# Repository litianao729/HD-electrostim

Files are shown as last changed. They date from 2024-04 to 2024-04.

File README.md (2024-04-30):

# A scalable, non-invasive, high-frequency stimulator for tactile sensory feedback

# Description
This project is used to support the thesis and paper. A scalable, non-invasive, high-frequency stimulator is developed in this work for tactile sensory feedback. The hardware design files, and software program files are contained in this GitHub project.
# Instruction
The folder named pcb contains three folders which correspond to three separate PCB boards of the stimulator. For each folder, the file with extension of .kicad_pro can be opened by KiCad software. One can modify the schematics and PCB layouts for a specific PCB design project. To utilize the design:
1.	Find the folder has “gerber” in its name. This folder contains the information to fabricate the board. 
2.	Upload that folder (or compress before uploading) to a PCB fabrication server such as PCBway. 
3.	Assemble the boards according to the components listed in the table with an extension name of .csv.
Software program codes to control the stimulator are saved in the rest folders. Folders named whole_time_current_pulse and whole_time_voltage_pulse only has Arduino IDE sketch. These sketches are example codes to run the stimulator producing endless square waveform with constant current or voltage amplitude. To utilize these codes:
1.	Download the entire folder and open the sketch (extension name is .ino) via Arduino IDE.
2.	Upload the sketch to the stimulator (connected with your laptop).
3.	Measure the signal from the electrode outputs (align with the settings in the sketch).
Folder named switching_speed_test only has Arduino sketch. This sketch is used to test the switch speed of the electrode switchboard of the stimulator. To utilize this code:
1.	Download the entire folder and open the sketch (extension name is .ino) via Arduino IDE.
2.	Upload the sketch to the stimulator (connected with your laptop).
3.	Measure the signal from the electrode outputs (align with the settings in the sketch) with a oscilloscope to observe the time delay between electrode disconnection and reconnection (electrode switching event is defined as a disconnection of the old electrode and a connection of another electrode)
Other folders contain not only Arduino IDE sketch but also MATLAB script (extension name: .m) or live script (extension name: .mlx). The MATLAB scripts determine the values of the parameters defined in the Arduino IDE sketches. By serial communication, these values are transferred to the IDE interface. For each folder, to utilize the codes:
Download the folder. Open the Arduino IDE sketch and MATLAB script with Arduino IDE and MATLAB respectively.
Upload the sketch to the stimulator (connected with your laptop).
Run the first section in the MATLAB script (to establish serial communication between MATLAB and Arduino IDE).
If there is no error, run the rest sections of the script.
For live script, interactive controls are used to define the parameter values. One can change the values as the program is running.

# Notifications and troubleshooting:
The connection between MATLAB and Arduino IDE is achieved through serial communication. When using MATLAB script as the parameter inputs, you cannot use Serial monitor tool of the Arduino IDE.
Sometimes error might occur when running the first section of the MATLAB script to establish serial communication. To solve this issue, you can check if serial monitor tool is being used and reupload the sketch.

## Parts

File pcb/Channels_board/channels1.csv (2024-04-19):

Source: | /Users/tianaoli/Library/CloudStorage/OneDrive-JohnsHopkins/Electrostimulator/electrostimulatorv3/electrostimulatorV3_pcbdesign/channels1/channels1.kicad_sch
Date: | 2023 December 08, Friday 15:54:42
Tool: | Eeschema 7.0.6-0
Generator: | /Applications/KiCad/KiCad.app/Contents/SharedSupport/plugins/bom_csv_grouped_by_value_with_fp.py
Component Count: | 71
Ref | Qnty | Value | Cmp name | Footprint | Description | Vendor | DNP | name | we have | we need | we buy | link
C1, C3, C5, C20, C22 | 5 | 10uF | C | Capacitor_SMD:C_0805_2012Metric_Pad1.18x1.45mm_HandSolder | Unpolarized capacitor |  |  |  | 8 | 5 | 10
C2, C4, C6, C17, C18, C19, C21, C23, C24 | 9 | 0.1uF | C | Capacitor_SMD:C_0805_2012Metric_Pad1.18x1.45mm_HandSolder | Unpolarized capacitor |  |  |  | >20 | 9 | 0
C7, C8, C9, C10, C11, C12, C13, C14 | 8 | 1uF | C_Polarized | Capacitor_SMD:C_0805_2012Metric_Pad1.18x1.45mm_HandSolder | Polarized capacitor |  |  |  | >100 | 8 | 0
C15, C16 | 2 | 100 nF | C | Capacitor_SMD:C_0805_2012Metric_Pad1.18x1.45mm_HandSolder | Unpolarized capacitor |  |  |  | >20 | 2 | 20
C25, C26, C27, C28 | 4 | 100nF | C | Capacitor_SMD:C_0805_2012Metric_Pad1.18x1.45mm_HandSolder | Unpolarized capacitor |  |  |  | >20 | 4 | \
IC1 | 1 | MAX5322EAI+ | MAX5322EAI+ | MAX5322:SOP65P778X199-28N | Maxim MAX5322EAI+, 2-channel 12 bit Serial DAC, 28-Pin SSOP |  |  |  | 8 | 1 | 0
IC2, IC3 | 2 | MAX14757EUE+T | MAX14757EUE+T | MAX14757:SOP65P640X110-16N | Analog Switch ICs Quad SPST +70V Analog Switches |  |  |  | 9 | 2 | 15
IC4, IC5 | 2 | MAX11156ETC+ | MAX11156ETC+ | MAX11156:SON50P300X300X80-13N | Analog to Digital Converters - ADC 18-Bit, 500ksps, 5V SAR ADC with Internal Reference in TDFN |  |  |  | 4 | 2 | 0
IC6, IC7, IC8, IC9 | 4 | OPA455IDDA | OPA455IDDA | OPA455:SOIC127P600X170-9N | 150-V, WIDE BANDWIDTH 6.5-MHZ, H |  |  |  | 0 | 4 | 10
J1, J3 | 2 | Conn_01x07_Socket | Conn_01x07_Socket | Connector_PinSocket_2.54mm:PinSocket_1x07_P2.54mm_Vertical | Generic connector, single row, 01x07, script generated |  |  |  | \ | 2 | \
J2 | 1 | Conn_01x02_Pin | Conn_01x02_Pin | Connector_PinHeader_2.54mm:PinHeader_1x02_P2.54mm_Vertical | Generic connector, single row, 01x02, script generated |  |  |  | \ | 1 | \
R1, R2 | 2 | 240 | R | Resistor_SMD:R_0805_2012Metric_Pad1.20x1.40mm_HandSolder | Resistor |  |  |  | 7 | 2 | 0
R3, R5 | 2 | 10k | R | Resistor_SMD:R_0805_2012Metric_Pad1.20x1.40mm_HandSolder | Resistor |  |  |  | 6 | 2 | 0
R4, R6 | 2 | 50k | R | Resistor_SMD:R_0805_2012Metric_Pad1.20x1.40mm_HandSolder | Resistor |  |  |  | 6 | 2 | 0
R7, R12 | 2 | 101k | R | Resistor_SMD:R_0805_2012Metric_Pad1.20x1.40mm_HandSolder | Resistor |  |  |  | 7 | 2 | 0
R8, R9, R10, R13, R14, R15 | 6 | 100k | R | Resistor_SMD:R_0805_2012Metric_Pad1.20x1.40mm_HandSolder | Resistor |  |  |  | 1 | 6 | 10
R11, R16 | 2 | 1k | R | Resistor_SMD:R_0805_2012Metric_Pad1.20x1.40mm_HandSolder | Resistor |  |  |  | 7 | 2 | 0
TP1, TP2, TP3, TP4, TP5, TP6, TP7, TP8, TP9, TP10, TP11, TP12 | 12 | TestPoint | TestPoint | TestPoint:TestPoint_Pad_1.0x1.0mm | test point |  |  |  |  | 12
U1 | 1 | DEV-15583 | DEV-15583 | DEV-15583:MODULE_DEV-15583 |  |  |  |  | \ | 1 | \
U2, U3 | 2 | INA149AID | INA149AID | INA149:D0008A_N |  |  |  |  | 1 | 2 | 5

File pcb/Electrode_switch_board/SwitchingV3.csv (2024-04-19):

Source: | /Users/tianaoli/Library/CloudStorage/OneDrive-JohnsHopkins/Electrostimulator/electrostimulatorv3/electrostimulatorV3_pcbdesign/SwitchingV3/SwitchingV3.kicad_sch
Date: | 2023 December 08, Friday 15:54:25
Tool: | Eeschema 7.0.6-0
Generator: | /Applications/KiCad/KiCad.app/Contents/SharedSupport/plugins/bom_csv_grouped_by_value_with_fp.py
Component Count: | 74
Ref | Qnty | Value | Cmp name | Footprint | Description | Vendor | DNP | name | we have | we need | we buy | link
C1, C2, C3, C4, C5, C6, C7, C8, C9, C10, C11, C12, C13, C14, C15, C16, C17, C18, C19, C20, C21, C22, C23, C24 | 24 | 1uF | C | Capacitor_SMD:C_0805_2012Metric | Unpolarized capacitor |  |  |  | >100 | 24 | 0
IC1, IC4 | 2 |  | SN74LVC1G3157DBVR | 74lvc1g373dbvre4:SOT95P280X145-6N | SINGLE-POLE, DOUBLE-THROW ANALOG SWITCH |  |  |  | 3 | 2 | 10
IC2, IC3, IC5, IC6 | 4 | CD74HC4067M | CD74HC4067M | cd74hc4067m:SOIC127P1030X265-24N | High Speed CMOS 16-Ch MUX/DEMUX 24P SOIC Texas Instruments CD74HC4067M, Multiplexer/Demultiplexer Single 16:1, 3 V, 5 V, 24-Pin SOIC |  |  |  | 0 | 4 | 10
IC7, IC8, IC9, IC10, IC11, IC12, IC13, IC14, IC15, IC16, IC17, IC18, IC19, IC20, IC21, IC22, IC23, IC24, IC25, IC26, IC27, IC28, IC29, IC30, IC31, IC32, IC33, IC34, IC35, IC36, IC37, IC38 | 32 | 74LVC1G373DBVRE4 | 74LVC1G373DBVRE4 | 74lvc1g373dbvre4:SOT95P280X145-6N | IC SNGL D-TYPE LATCH SOT23-6 |  |  |  | 18 | 32 | 50
IC39, IC40, IC41, IC42, IC43, IC44, IC45, IC46 | 8 | MAX14757EUE+T | MAX14757EUE+T | max14757eue:SOP65P640X110-16N | Analog Switch ICs Quad SPST +70V Analog Switches |  |  |  | 9 | 8 | \
J1 | 1 | Conn_01x04_Socket | Conn_01x04_Socket | Connector_PinSocket_2.54mm:PinSocket_1x04_P2.54mm_Vertical | Generic connector, single row, 01x04, script generated |  |  |  |  | 1
J2 | 1 | Conn_01x02_Socket | Conn_01x02_Socket | Connector_PinHeader_2.54mm:PinHeader_1x02_P2.54mm_Vertical | Generic connector, single row, 01x02, script generated |  |  |  |  | 1
J3 | 1 | Conn_01x07_Socket | Conn_01x07_Socket | Connector_PinHeader_2.54mm:PinHeader_1x07_P2.54mm_Vertical | Generic connector, single row, 01x07, script generated |  |  |  |  | 1
J4 | 1 | Conn_01x16_Pin | Conn_01x16_Pin | Connector_PinSocket_2.54mm:PinSocket_1x16_P2.54mm_Vertical | Generic connector, single row, 01x16, script generated |  |  |  |  | 1

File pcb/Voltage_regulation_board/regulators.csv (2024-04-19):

Source: | /Users/tianaoli/Library/CloudStorage/OneDrive-JohnsHopkins/Electrostimulator/electrostimulatorV4/pcbs/regulators/regulators.kicad_sch
Date: | 2024 January 17, Wednesday 19:40:57
Tool: | Eeschema 7.0.6-0
Generator: | /Applications/KiCad/KiCad.app/Contents/SharedSupport/plugins/bom_csv_grouped_by_value.py
Component Count: | 50
Collated Components:
Item | Qty | Reference(s) | Value | LibPart | Footprint | Datasheet | DNP | Height | Manufacturer_Name | Manufacturer_Part_Number | Mouser Part Number | Mouser Price/Stock
1 | 6 | C1, CIN_1, CN1, COUT1_1, COUT2_1, CP1 | 10uF | Device:C | Capacitor_SMD:C_1210_3225Metric_Pad1.33x2.70mm_HandSolder | ~
2 | 1 | C2 | 22uF | Device:C | Capacitor_SMD:C_0805_2012Metric_Pad1.18x1.45mm_HandSolder | ~
3 | 2 | CC1_1, CC2_1 | 47nF | Device:C | Capacitor_SMD:C_0805_2012Metric_Pad1.18x1.45mm_HandSolder | ~
4 | 4 | CN2, CN5, CP2, CP5 | 0.22uF | Device:C | Capacitor_SMD:C_0805_2012Metric_Pad1.18x1.45mm_HandSolder | ~
5 | 2 | CN3, CP3 | 1nF | Device:C | Capacitor_SMD:C_0805_2012Metric_Pad1.18x1.45mm_HandSolder | ~
6 | 4 | CN4, CP4, CVREF_1, CVREG_1 | 1uF | Device:C | Capacitor_SMD:C_0805_2012Metric_Pad1.18x1.45mm_HandSolder | ~
7 | 1 | CN6 | 0.1uF | Device:C | Capacitor_SMD:C_0805_2012Metric_Pad1.18x1.45mm_HandSolder | ~
8 | 2 | D1, D2 | DFLS240L-7 | Diode:DFLS240L-7 | Diode_SMD:D_PowerDI-123
9 | 3 | DN1, DN2, DP1 | RB068L150DDTE25 | RB068L150DDTE25:RB068L150DDTE25 | RB068L150:DIOM5026X220N | https://fscdn.rohm.com/en/products/databook/datasheet/discrete/diode/schottky_barrier/rb068l150ddte25-e.pdf |  | 2.2 | ROHM Semiconductor | RB068L150DDTE25 | 755-RB068L150DDTE25 | https://www.mouser.co.uk/ProductDetail/ROHM-Semiconductor/RB068L150DDTE25?qs=HXFqYaX1Q2wo%2F7dyRQhxHg%3D%3D
10 | 2 | IC1, IC2 | LT8365HMSE#PBF | LT8365HMSE#PBF:LT8365HMSE#PBF | LT8365:SOP50P490X110-17N | https://www.analog.com/media/en/technical-documentation/data-sheets/LT8365.pdf |  | 1.1 | Analog Devices | LT8365HMSE#PBF | 584-LT8365HMSE#PBF | https://www.mouser.co.uk/ProductDetail/Analog-Devices/LT8365HMSEPBF?qs=GBLSl2Akirvi5%252BAyHwg2vw%3D%3D
11 | 1 | J1 | Conn_01x06_Pin | Connector:Conn_01x06_Pin | Connector_PinHeader_2.54mm:PinHeader_1x06_P2.54mm_Horizontal | ~
12 | 1 | J2 | Conn_01x02_Socket | Connector:Conn_01x02_Socket | Connector_PinSocket_2.54mm:PinSocket_1x02_P2.54mm_Horizontal | ~
13 | 1 | L1_1 | 6.8uH | Device:L | Inductor_SMD:L_Coilcraft_XAL4040-XXX | ~
14 | 3 | L2_1, LN1, LP1 | 10uH | Device:L | Inductor_SMD:L_Coilcraft_XAL4040-XXX | ~
15 | 1 | RC1_1 | 22k | Device:R | Resistor_SMD:R_0805_2012Metric_Pad1.20x1.40mm_HandSolder | ~
16 | 1 | RC2_1 | 12k | Device:R | Resistor_SMD:R_0805_2012Metric_Pad1.20x1.40mm_HandSolder | ~
17 | 1 | RFB1_1 | 137k | Device:R | Resistor_SMD:R_0805_2012Metric_Pad1.20x1.40mm_HandSolder | ~
18 | 1 | RFB2_1 | 118k | Device:R | Resistor_SMD:R_0805_2012Metric_Pad1.20x1.40mm_HandSolder | ~
19 | 1 | RFT1_1 | 2.43M | Device:R | Resistor_SMD:R_0805_2012Metric_Pad1.20x1.40mm_HandSolder | ~
20 | 1 | RFT2_1 | 2.32M | Device:R | Resistor_SMD:R_0805_2012Metric_Pad1.20x1.40mm_HandSolder | ~
21 | 2 | RN1, RP1 | 107k | Device:R | Resistor_SMD:R_0805_2012Metric_Pad1.20x1.40mm_HandSolder | ~
22 | 2 | RN2, RP2 | 84.5k | Device:R | Resistor_SMD:R_0805_2012Metric_Pad1.20x1.40mm_HandSolder | ~
23 | 1 | RN3 | 24k | Device:R | Resistor_SMD:R_0805_2012Metric_Pad1.20x1.40mm_HandSolder | ~
24 | 2 | RN4, RP4 | 1M | Device:R | Resistor_SMD:R_0805_2012Metric_Pad1.20x1.40mm_HandSolder | ~
25 | 1 | RN5 | 20 | Device:R | Resistor_SMD:R_0805_2012Metric_Pad1.20x1.40mm_HandSolder | ~
26 | 1 | RP3 | 49.3k | Device:R | Resistor_SMD:R_0805_2012Metric_Pad1.20x1.40mm_HandSolder | ~
27 | 1 | U1 | ADP5070AREZ | Regulator_Switching:ADP5070AREZ | Package_SO:ETSSOP-20-1EP_4.4x6.5mm_P0.65mm_EP3x4.2mm | https://www.analog.com/media/en/technical-documentation/data-sheets/ADP5070.pdf
28 | 1 | U2 | AZ1117IH-5.0TRG1 | New:AZ1117IH-5.0TRG1 | Package_TO_SOT_SMD:SOT-223-3_TabPin2

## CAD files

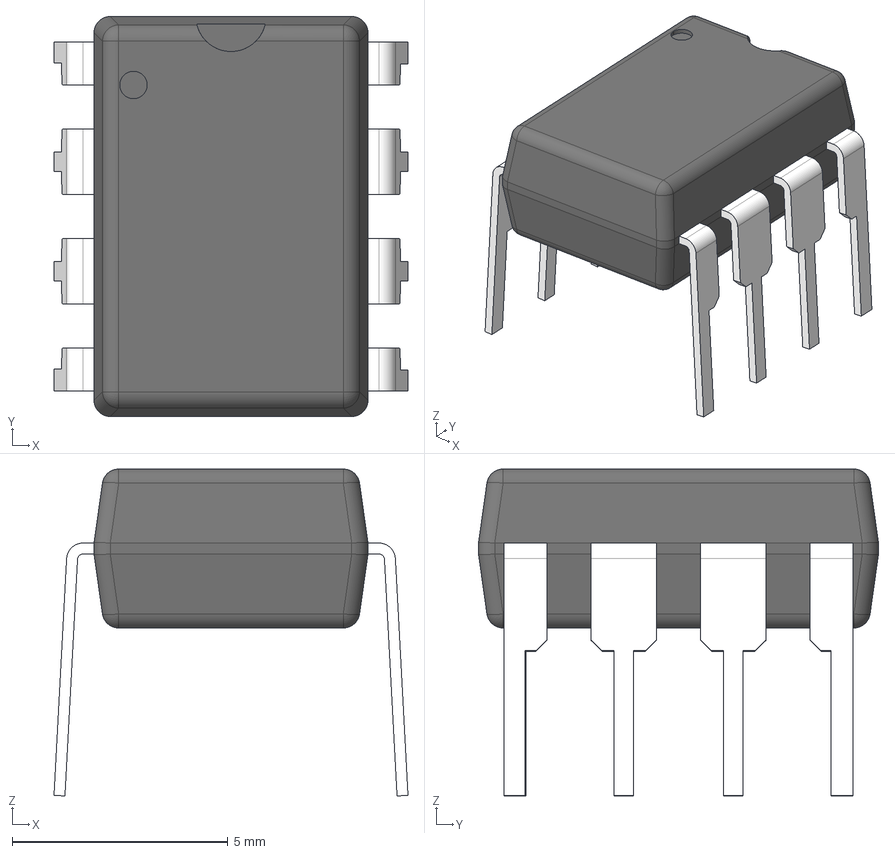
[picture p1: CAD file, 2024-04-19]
pcb/Channels_board/LIB_LM358N (ADC OP AMP)/LM358N/3D/LM358N.stp
8.20 x 9.27 x 7.58 mm
BODY_P0008A
LEAD_P0008A x 4
LD_LHALF_P0008A x 2
LD_RHALF_P0008A x 2

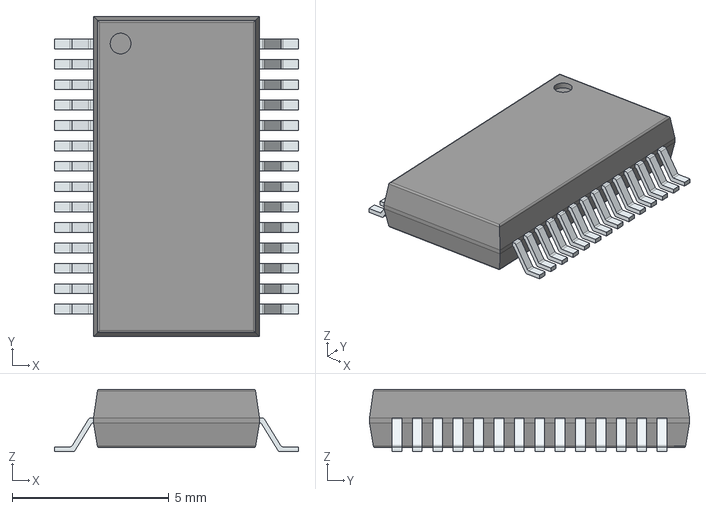
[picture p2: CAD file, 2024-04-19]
pcb/Channels_board/LIB_MAX5322EAI+ (DAC)/MAX5322EAI+/3D/MAX5322EAI+.stp
7.78 x 10.2 x 1.99 mm
PinsArrayLR

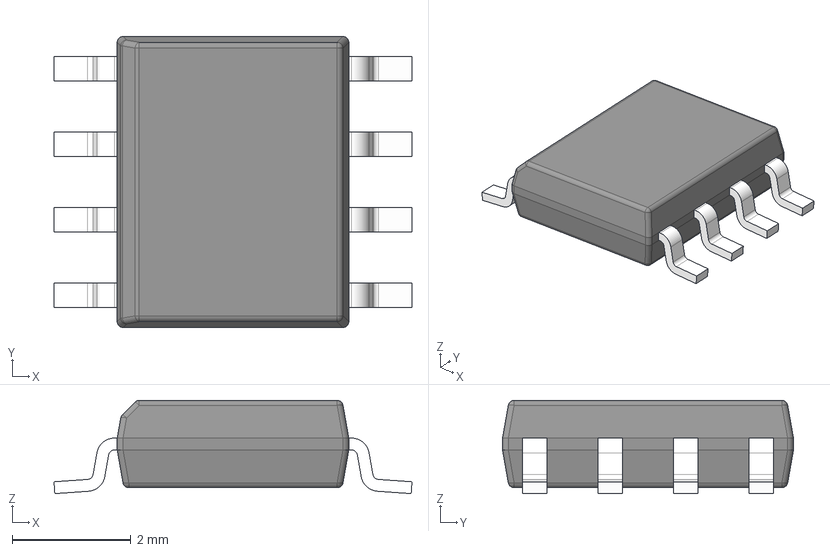
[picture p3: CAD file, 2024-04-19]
pcb/Channels_board/LIB_OPA455IDDA (HIGH VOLTAGE OP AMP)/OPA455IDDA/3D/OPA455IDDA.stp
6.03 x 4.90 x 1.57 mm
BODY-SO
LEAD-SO x 8
THERMALPAD-SO

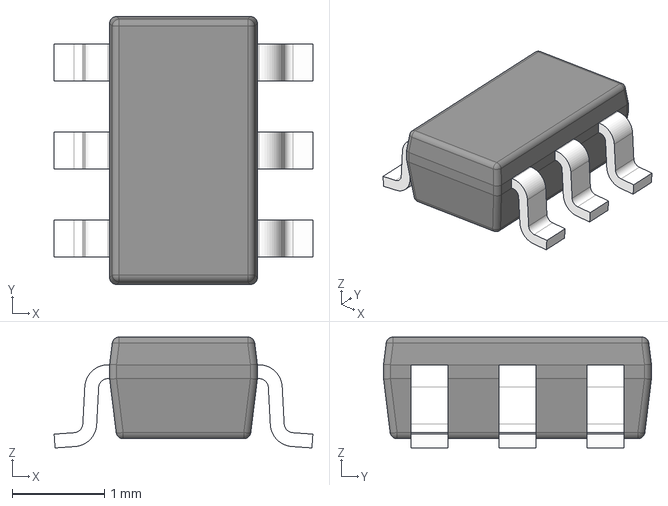
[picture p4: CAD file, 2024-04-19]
pcb/Electrode_switch_board/LIB_74LVC1G373DBVRE4/74LVC1G373DBVRE4/3D/74LVC1G373DBVRE4.stp
2.80 x 2.90 x 1.20 mm
BODY-SOT
LEAD-SOT x 6

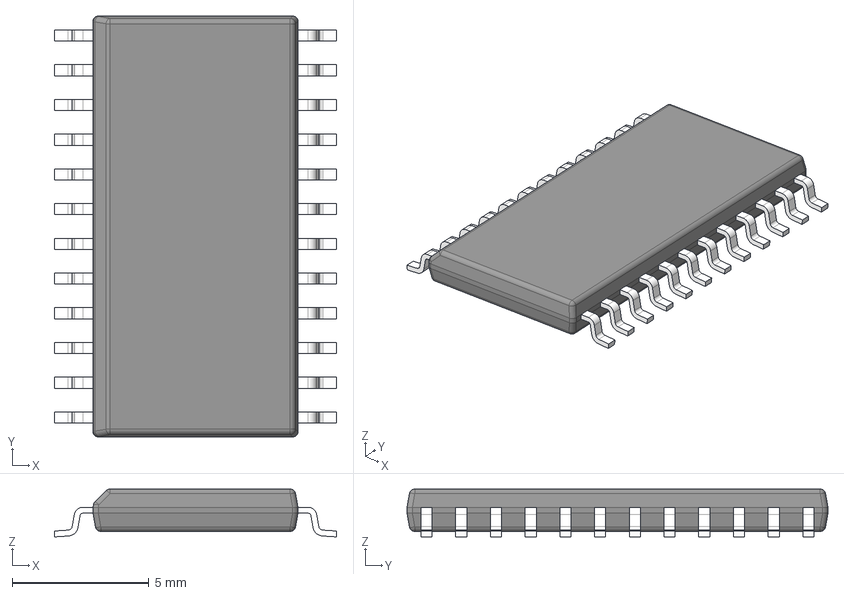
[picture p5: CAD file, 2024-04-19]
pcb/Electrode_switch_board/LIB_CD74HC4067M/CD74HC4067M/3D/CD74HC4067M.stp
10.3 x 15.4 x 1.75 mm
BODY-SO
LEAD-SO x 24
PIN1-ID

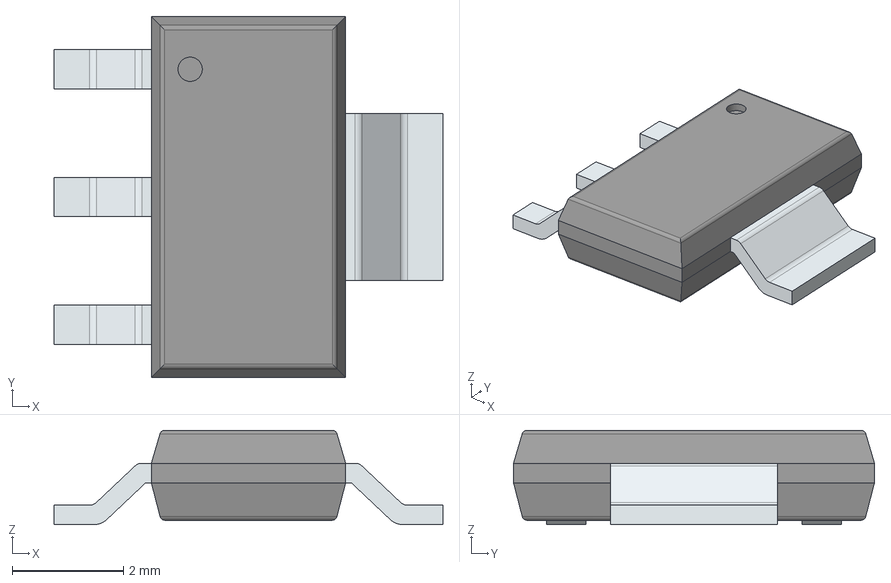
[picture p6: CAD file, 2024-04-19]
pcb/Voltage_regulation_board/LIB_AZ1117IH-5.0TRG1/AZ1117IH-5.0TRG1/3D/AZ1117IH-5.0TRG1.stp
7.00 x 6.50 x 1.70 mm
PinsArrayL
FilletPinR

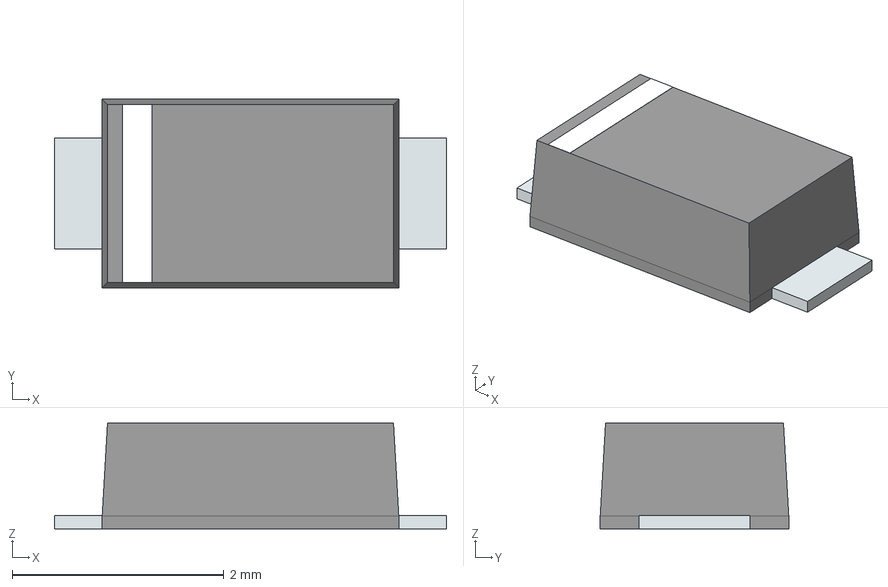
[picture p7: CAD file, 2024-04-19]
pcb/Voltage_regulation_board/LIB_DFLS1150-7/DFLS1150-7/3D/DFLS1150-7.stp
3.70 x 1.78 x 1.00 mm
PinKIdent
PinK
PinA

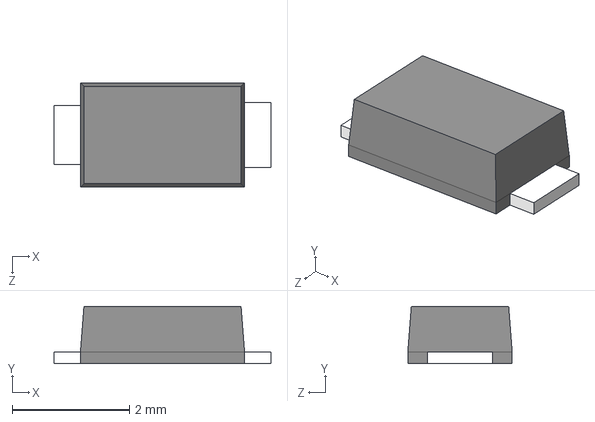
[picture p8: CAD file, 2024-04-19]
pcb/Voltage_regulation_board/LIB_DFLS240-7/DFLS240-7/3D/DFLS240-7.stp
3.70 x 0.98 x 1.78 mm

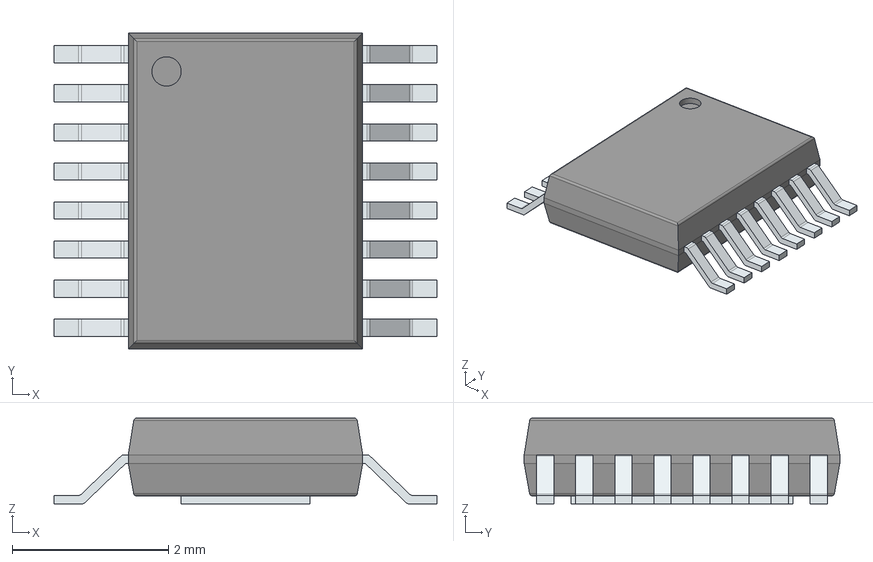
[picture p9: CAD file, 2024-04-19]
pcb/Voltage_regulation_board/LIB_LT8365HMSE#PBF/LT8365HMSE#PBF/3D/LT8365HMSE#PBF.stp
4.90 x 4.04 x 1.10 mm
PinsArrayLR
ThermalPad

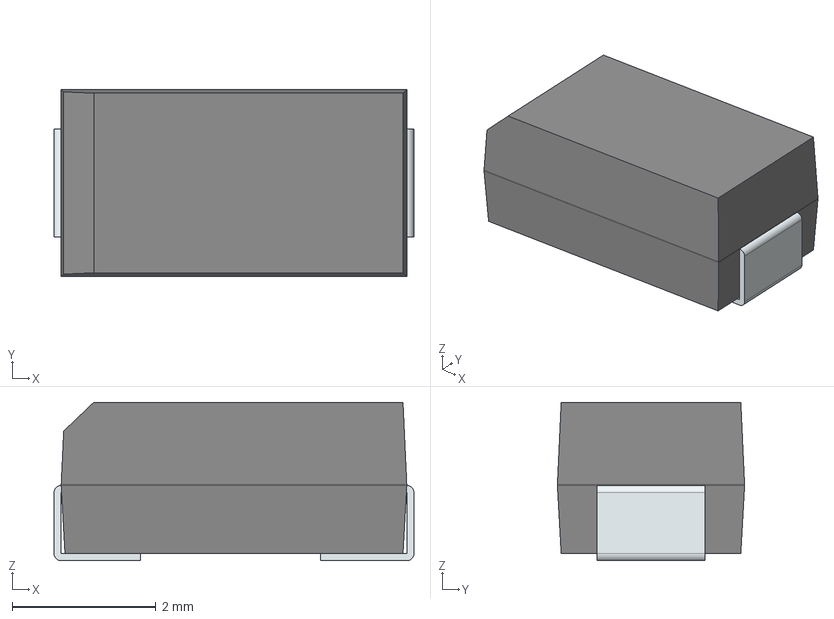
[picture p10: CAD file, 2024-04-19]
pcb/Voltage_regulation_board/LIB_RB068L150DDTE25/RB068L150DDTE25/3D/RB068L150DDTE25.stp
5.00 x 2.60 x 2.20 mm
FilletPin1
FilletPin2

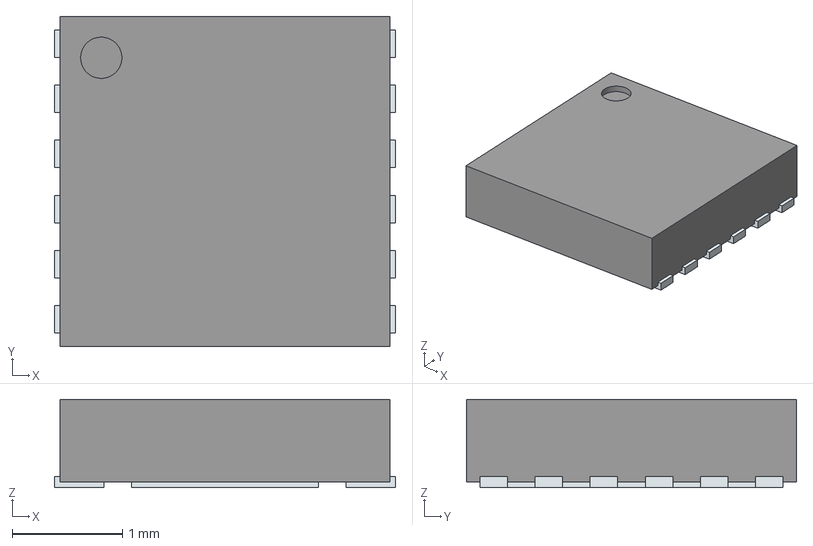
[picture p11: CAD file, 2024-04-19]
pcb/Channels_board/LIB_MAX11156ETC+ (1)/MAX11156ETC+/3D/MAX11156ETC+.stp
3.10 x 3.00 x 0.8 mm
ThermalPin
PinsArrayLR

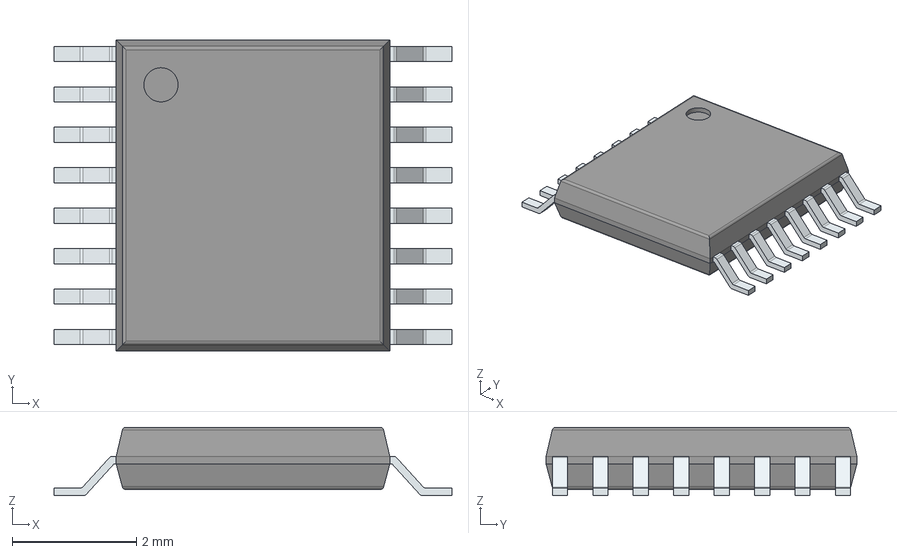
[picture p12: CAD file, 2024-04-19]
pcb/Channels_board/LIB_MAX14757EUE+T/MAX14757EUE+T/3D/MAX14757EUE+T.stp
6.40 x 5.00 x 1.10 mm
PinsArrayLR

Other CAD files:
pcb/Channels_board/LIB_LM358N (ADC OP AMP)/LM358N/Allegro/dip762w56p254l960h393q8n.psm
pcb/Channels_board/LIB_LM358N (ADC OP AMP)/LM358N/DEHDL/lm358n/chips/chips.prt
pcb/Channels_board/LIB_MAX11156ETC+ (1)/MAX11156ETC+/Allegro/son50p300x300x80-13n.psm
pcb/Channels_board/LIB_MAX11156ETC+ (1)/MAX11156ETC+/DEHDL/max11156etc_/chips/chips.prt
pcb/Channels_board/LIB_MAX14757EUE+T/MAX14757EUE+T/Allegro/sop65p640x110-16n.psm
pcb/Channels_board/LIB_MAX14757EUE+T/MAX14757EUE+T/DEHDL/max14757eue_t/chips/chips.prt
pcb/Channels_board/LIB_MAX5322EAI+ (DAC)/MAX5322EAI+/Allegro/sop65p778x199-28n.psm
pcb/Channels_board/LIB_MAX5322EAI+ (DAC)/MAX5322EAI+/DEHDL/max5322eai_/chips/chips.prt
pcb/Channels_board/LIB_OPA455IDDA (HIGH VOLTAGE OP AMP)/OPA455IDDA/Allegro/soic127p600x170-9n.psm
pcb/Channels_board/LIB_OPA455IDDA (HIGH VOLTAGE OP AMP)/OPA455IDDA/DEHDL/opa455idda/chips/chips.prt
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

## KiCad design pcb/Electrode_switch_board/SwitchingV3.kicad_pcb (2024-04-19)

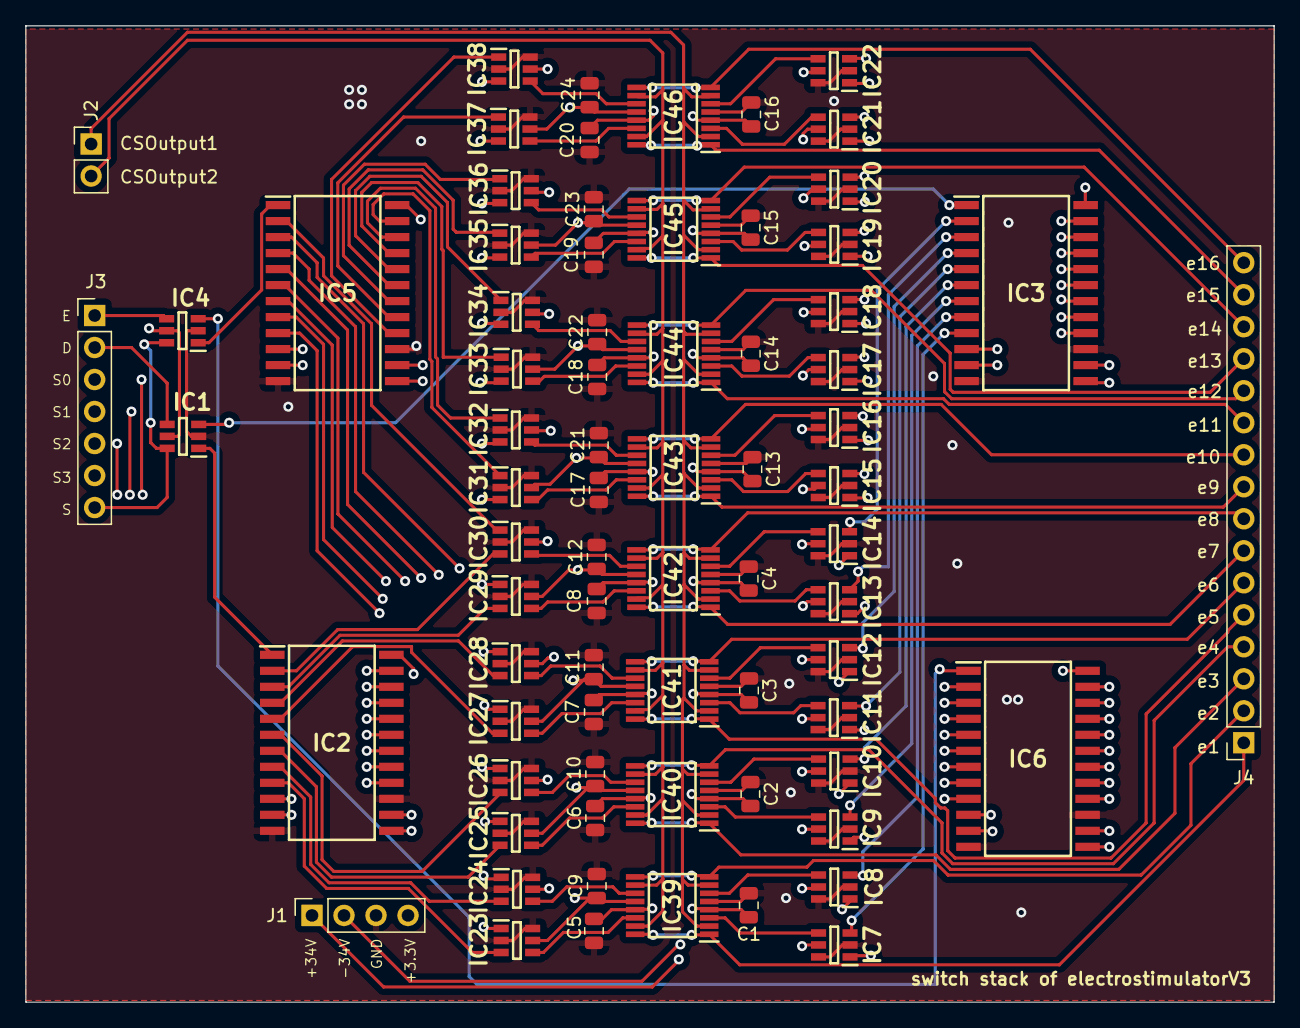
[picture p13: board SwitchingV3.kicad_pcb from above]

Board: 4 copper layers, 99.1 x 77.5 mm, 74 parts (0 on the bottom side), 129 nets.

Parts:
C1, C2, C3, C4, C5, C6, C7, C8, C9, C10, C11, C12, C13, C14, C15, C16, C17, C18, C19, C20, C21, C22, C23, C24: 1uF; C_0805_2012Metric
IC1, IC4: SN74LVC1G3157DBVR; SOT95P280X145-6N
IC2, IC3, IC5, IC6: CD74HC4067M; SOIC127P1030X265-24N
IC7, IC8, IC9, IC10, IC11, IC12, IC13, IC14, IC15, IC16, IC17, IC18, IC19, IC20, IC21, IC22, IC23, IC24, IC25, IC26, IC27, IC28, IC29, IC30, IC31, IC32, IC33, IC34, IC35, IC36, IC37, IC38: 74LVC1G373DBVRE4; SOT95P280X145-6N
IC39, IC40, IC41, IC42, IC43, IC44, IC45, IC46: MAX14757EUE+T; SOP65P640X110-16N
J1: Conn_01x04_Socket; PinSocket_1x04_P2.54mm_Vertical
J2: Conn_01x02_Socket; PinHeader_1x02_P2.54mm_Vertical
J3: Conn_01x07_Socket; PinHeader_1x07_P2.54mm_Vertical
J4: Conn_01x16_Pin; PinSocket_1x16_P2.54mm_Vertical

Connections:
+3.3V: C9.1, C10.1, C11.1, C12.1, C21.1, C22.1, C23.1, C24.1, IC1.5 (VCC), IC2.24 (VCC), IC3.24 (VCC), IC4.5 (VCC), IC5.24 (VCC), IC6.24 (VCC), IC7.5 (VCC), IC8.5 (VCC), IC9.5 (VCC), IC10.5 (VCC), IC11.5 (VCC), IC12.5 (VCC), IC13.5 (VCC), IC14.5 (VCC), IC15.5 (VCC), IC16.5 (VCC), IC17.5 (VCC), IC18.5 (VCC), IC19.5 (VCC), IC20.5 (VCC), IC21.5 (VCC), IC22.5 (VCC), IC23.5 (VCC), IC24.5 (VCC), IC25.5 (VCC), IC26.5 (VCC), IC27.5 (VCC), IC28.5 (VCC), IC29.5 (VCC), IC30.5 (VCC), IC31.5 (VCC), IC32.5 (VCC), IC33.5 (VCC), IC34.5 (VCC), IC35.5 (VCC), IC36.5 (VCC), IC37.5 (VCC), IC38.5 (VCC), IC39.12 (VL), IC40.12 (VL), IC41.12 (VL), IC42.12 (VL), IC43.12 (VL), IC44.12 (VL), IC45.12 (VL), IC46.12 (VL), J1.4
+34V: C5.1, C6.1, C7.1, C8.1, C17.1, C18.1, C19.1, C20.1, IC39.13 (VDD), IC40.13 (VDD), IC41.13 (VDD), IC42.13 (VDD), IC43.13 (VDD), IC44.13 (VDD), IC45.13 (VDD), IC46.13 (VDD), J1.1
-34V: C1.1, C2.1, C3.1, C4.1, C13.1, C14.1, C15.1, C16.1, IC39.4 (VSS), IC40.4 (VSS), IC41.4 (VSS), IC42.4 (VSS), IC43.4 (VSS), IC44.4 (VSS), IC45.4 (VSS), IC46.4 (VSS), J1.2
CSOutput1: IC39.2 (B1), IC39.7 (B4), IC40.2 (B1), IC40.7 (B4), IC41.2 (B1), IC41.7 (B4), IC42.2 (B1), IC42.7 (B4), IC43.2 (B1), IC43.7 (B4), IC44.2 (B1), IC44.7 (B4), IC45.2 (B1), IC45.7 (B4), IC46.2 (B1), IC46.7 (B4), J2.1
CSOutput2: IC39.10 (B3), IC39.15 (B2), IC40.10 (B3), IC40.15 (B2), IC41.10 (B3), IC41.15 (B2), IC42.10 (B3), IC42.15 (B2), IC43.10 (B3), IC43.15 (B2), IC44.10 (B3), IC44.15 (B2), IC45.10 (B3), IC45.15 (B2), IC46.10 (B3), IC46.15 (B2), J2.2
D1_1: IC3.9 (I0), IC7.3 (D)
D1_2: IC2.9 (I0), IC23.3 (D)
D2_1: IC3.8 (I1), IC8.3 (D)
D2_2: IC2.8 (I1), IC24.3 (D)
D3_1: IC3.7 (I2), IC9.3 (D)
D3_2: IC2.7 (I2), IC25.3 (D)
D4_1: IC3.6 (I3), IC10.3 (D)
D4_2: IC2.6 (I3), IC26.3 (D)
D5_1: IC3.5 (I4), IC11.3 (D)
D5_2: IC2.5 (I4), IC27.3 (D)
D6_1: IC3.4 (I5), IC12.3 (D)
D6_2: IC2.4 (I5), IC28.3 (D)
D7_1: IC3.3 (I6), IC13.3 (D)
D7_2: IC2.3 (I6), IC29.3 (D)
D8_1: IC3.2 (I7), IC14.3 (D)
D8_2: IC2.2 (I7), IC30.3 (D)
D9_1: IC3.23 (I8), IC15.3 (D)
D9_2: IC2.23 (I8), IC31.3 (D)
D10_1: IC3.22 (I9), IC16.3 (D)
D10_2: IC2.22 (I9), IC32.3 (D)
D11_1: IC3.21 (I10), IC17.3 (D)
D11_2: IC2.21 (I10), IC33.3 (D)
D12_1: IC3.20 (I11), IC18.3 (D)
D12_2: IC2.20 (I11), IC34.3 (D)
D13_1: IC3.19 (I12), IC19.3 (D)
D13_2: IC2.19 (I12), IC35.3 (D)
D14_1: IC3.18 (I13), IC20.3 (D)
D14_2: IC2.18 (I13), IC36.3 (D)
D15_1: IC3.17 (I14), IC21.3 (D)
D15_2: IC2.17 (I14), IC37.3 (D)
D16_1: IC3.16 (I15), IC22.3 (D)
D16_2: IC2.16 (I15), IC38.3 (D)
D_control: IC1.4 (A), J3.2
E1_1: IC6.9 (I0), IC7.1 (LE)
E1_2: IC5.9 (I0), IC23.1 (LE)
E2_1: IC6.8 (I1), IC8.1 (LE)
E2_2: IC5.8 (I1), IC24.1 (LE)
E3_1: IC6.7 (I2), IC9.1 (LE)
E3_2: IC5.7 (I2), IC25.1 (LE)
E4_1: IC6.6 (I3), IC10.1 (LE)
E4_2: IC5.6 (I3), IC26.1 (LE)
E5_1: IC6.5 (I4), IC11.1 (LE)
E5_2: IC5.5 (I4), IC27.1 (LE)
E6_1: IC6.4 (I5), IC12.1 (LE)
E6_2: IC5.4 (I5), IC28.1 (LE)
E7_1: IC6.3 (I6), IC13.1 (LE)
E7_2: IC5.3 (I6), IC29.1 (LE)
E8_1: IC6.2 (I7), IC14.1 (LE)
E8_2: IC5.2 (I7), IC30.1 (LE)
E9_1: IC6.23 (I8), IC15.1 (LE)
E9_2: IC5.23 (I8), IC31.1 (LE)
E10_1: IC6.22 (I9), IC16.1 (LE)
E10_2: IC5.22 (I9), IC32.1 (LE)
E11_1: IC6.21 (I10), IC17.1 (LE)
E11_2: IC5.21 (I10), IC33.1 (LE)
E12_1: IC6.20 (I11), IC18.1 (LE)
E12_2: IC5.20 (I11), IC34.1 (LE)
E13_1: IC6.19 (I12), IC19.1 (LE)
E13_2: IC5.19 (I12), IC35.1 (LE)
E14_1: IC6.18 (I13), IC20.1 (LE)
E14_2: IC5.18 (I13), IC36.1 (LE)
E15_1: IC6.17 (I14), IC21.1 (LE)
E15_2: IC5.17 (I14), IC37.1 (LE)
E16_1: IC6.16 (I15), IC22.1 (LE)
E16_2: IC5.16 (I15), IC38.1 (LE)
E_control: IC4.4 (A), J3.1
GND: C1.2, C2.2, C3.2, C4.2, C5.2, C6.2, C7.2, C8.2, C9.2, C10.2, C11.2, C12.2, C13.2, C14.2, C15.2, C16.2, C17.2, C18.2, C19.2, C20.2, C21.2, C22.2, C23.2, C24.2, IC1.2 (GND), IC2.12 (GND), IC2.15 (~E), IC3.12 (GND), IC3.15 (~E), IC4.2 (GND), IC5.12 (GND), IC5.15 (~E), IC6.12 (GND), IC6.15 (~E), IC7.2 (GND), IC7.6 (~OE), IC8.2 (GND), IC8.6 (~OE), IC9.2 (GND), IC9.6 (~OE), IC10.2 (GND), IC10.6 (~OE), IC11.2 (GND), IC11.6 (~OE), IC12.2 (GND), IC12.6 (~OE), IC13.2 (GND), IC13.6 (~OE), IC14.2 (GND), IC14.6 (~OE), IC15.2 (GND), IC15.6 (~OE), IC16.2 (GND), IC16.6 (~OE), IC17.2 (GND), IC17.6 (~OE), IC18.2 (GND), IC18.6 (~OE), IC19.2 (GND), IC19.6 (~OE), IC20.2 (GND), IC20.6 (~OE), IC21.2 (GND), IC21.6 (~OE), IC22.2 (GND), IC22.6 (~OE), IC23.2 (GND), IC23.6 (~OE), IC24.2 (GND), IC24.6 (~OE), IC25.2 (GND), IC25.6 (~OE), IC26.2 (GND), IC26.6 (~OE), IC27.2 (GND), IC27.6 (~OE), IC28.2 (GND), IC28.6 (~OE), IC29.2 (GND), IC29.6 (~OE), IC30.2 (GND), IC30.6 (~OE), IC31.2 (GND), IC31.6 (~OE), IC32.2 (GND), IC32.6 (~OE), IC33.2 (GND), IC33.6 (~OE), IC34.2 (GND), IC34.6 (~OE), IC35.2 (GND), IC35.6 (~OE), IC36.2 (GND), IC36.6 (~OE), IC37.2 (GND), IC37.6 (~OE), IC38.2 (GND), IC38.6 (~OE), IC39.5 (GND), IC40.5 (GND), IC41.5 (GND), IC42.5 (GND), IC43.5 (GND), IC44.5 (GND), IC45.5 (GND), IC46.5 (GND), J1.3
unnamed: IC1.3 (B1), IC3.1 (COMMON_INPUT/OUTPUT)
unnamed: IC1.1 (B2), IC2.1 (COMMON_INPUT/OUTPUT)
unnamed: IC4.3 (B1), IC6.1 (COMMON_INPUT/OUTPUT)
unnamed: IC4.1 (B2), IC5.1 (COMMON_INPUT/OUTPUT)
Q1_1: IC7.4 (Q), IC39.3 (EN1)
Q1_2: IC23.4 (Q), IC39.14 (EN2)
Q2_1: IC8.4 (Q), IC39.6 (EN4)
Q2_2: IC24.4 (Q), IC39.11 (EN3)
Q3_1: IC9.4 (Q), IC40.3 (EN1)
Q3_2: IC25.4 (Q), IC40.14 (EN2)
Q4_1: IC10.4 (Q), IC40.6 (EN4)
Q4_2: IC26.4 (Q), IC40.11 (EN3)
Q5_1: IC11.4 (Q), IC41.3 (EN1)
Q5_2: IC27.4 (Q), IC41.14 (EN2)
Q6_1: IC12.4 (Q), IC41.6 (EN4)
Q6_2: IC28.4 (Q), IC41.11 (EN3)
Q7_1: IC13.4 (Q), IC42.3 (EN1)
Q7_2: IC29.4 (Q), IC42.14 (EN2)
Q8_1: IC14.4 (Q), IC42.6 (EN4)
Q8_2: IC30.4 (Q), IC42.11 (EN3)
Q9_1: IC15.4 (Q), IC43.3 (EN1)
Q9_2: IC31.4 (Q), IC43.14 (EN2)
Q10_1: IC16.4 (Q), IC43.6 (EN4)
Q10_2: IC32.4 (Q), IC43.11 (EN3)
Q11_1: IC17.4 (Q), IC44.3 (EN1)
Q11_2: IC33.4 (Q), IC44.14 (EN2)
Q12_1: IC18.4 (Q), IC44.6 (EN4)
Q12_2: IC34.4 (Q), IC44.11 (EN3)
Q13_1: IC19.4 (Q), IC45.3 (EN1)
Q13_2: IC35.4 (Q), IC45.14 (EN2)
Q14_1: IC20.4 (Q), IC45.6 (EN4)
Q14_2: IC36.4 (Q), IC45.11 (EN3)
Q15_1: IC21.4 (Q), IC46.3 (EN1)
Q15_2: IC37.4 (Q), IC46.14 (EN2)
Q16_1: IC22.4 (Q), IC46.6 (EN4)
Q16_2: IC38.4 (Q), IC46.11 (EN3)
S: IC1.6 (S), IC4.6 (S), J3.7
S0: IC2.10 (S0), IC3.10 (S0), IC5.10 (S0), IC6.10 (S0), J3.3
S1: IC2.11 (S1), IC3.11 (S1), IC5.11 (S1), IC6.11 (S1), J3.4
S2: IC2.14 (S2), IC3.14 (S2), IC5.14 (S2), IC6.14 (S2), J3.5
S3: IC2.13 (S3), IC3.13 (S3), IC5.13 (S3), IC6.13 (S3), J3.6
e1: IC39.1 (A1), IC39.16 (A2), J4.1
e2: IC39.8 (A4), IC39.9 (A3), J4.2
e3: IC40.1 (A1), IC40.16 (A2), J4.3
e4: IC40.8 (A4), IC40.9 (A3), J4.4
e5: IC41.1 (A1), IC41.16 (A2), J4.5
e6: IC41.8 (A4), IC41.9 (A3), J4.6
e7: IC42.1 (A1), IC42.16 (A2), J4.7
e8: IC42.8 (A4), IC42.9 (A3), J4.8
e9: IC43.1 (A1), IC43.16 (A2), J4.9
e10: IC43.8 (A4), IC43.9 (A3), J4.10
e11: IC44.1 (A1), IC44.16 (A2), J4.11
e12: IC44.8 (A4), IC44.9 (A3), J4.12
e13: IC45.1 (A1), IC45.16 (A2), J4.13
e14: IC45.8 (A4), IC45.9 (A3), J4.14
e15: IC46.1 (A1), IC46.16 (A2), J4.15
e16: IC46.8 (A4), IC46.9 (A3), J4.16

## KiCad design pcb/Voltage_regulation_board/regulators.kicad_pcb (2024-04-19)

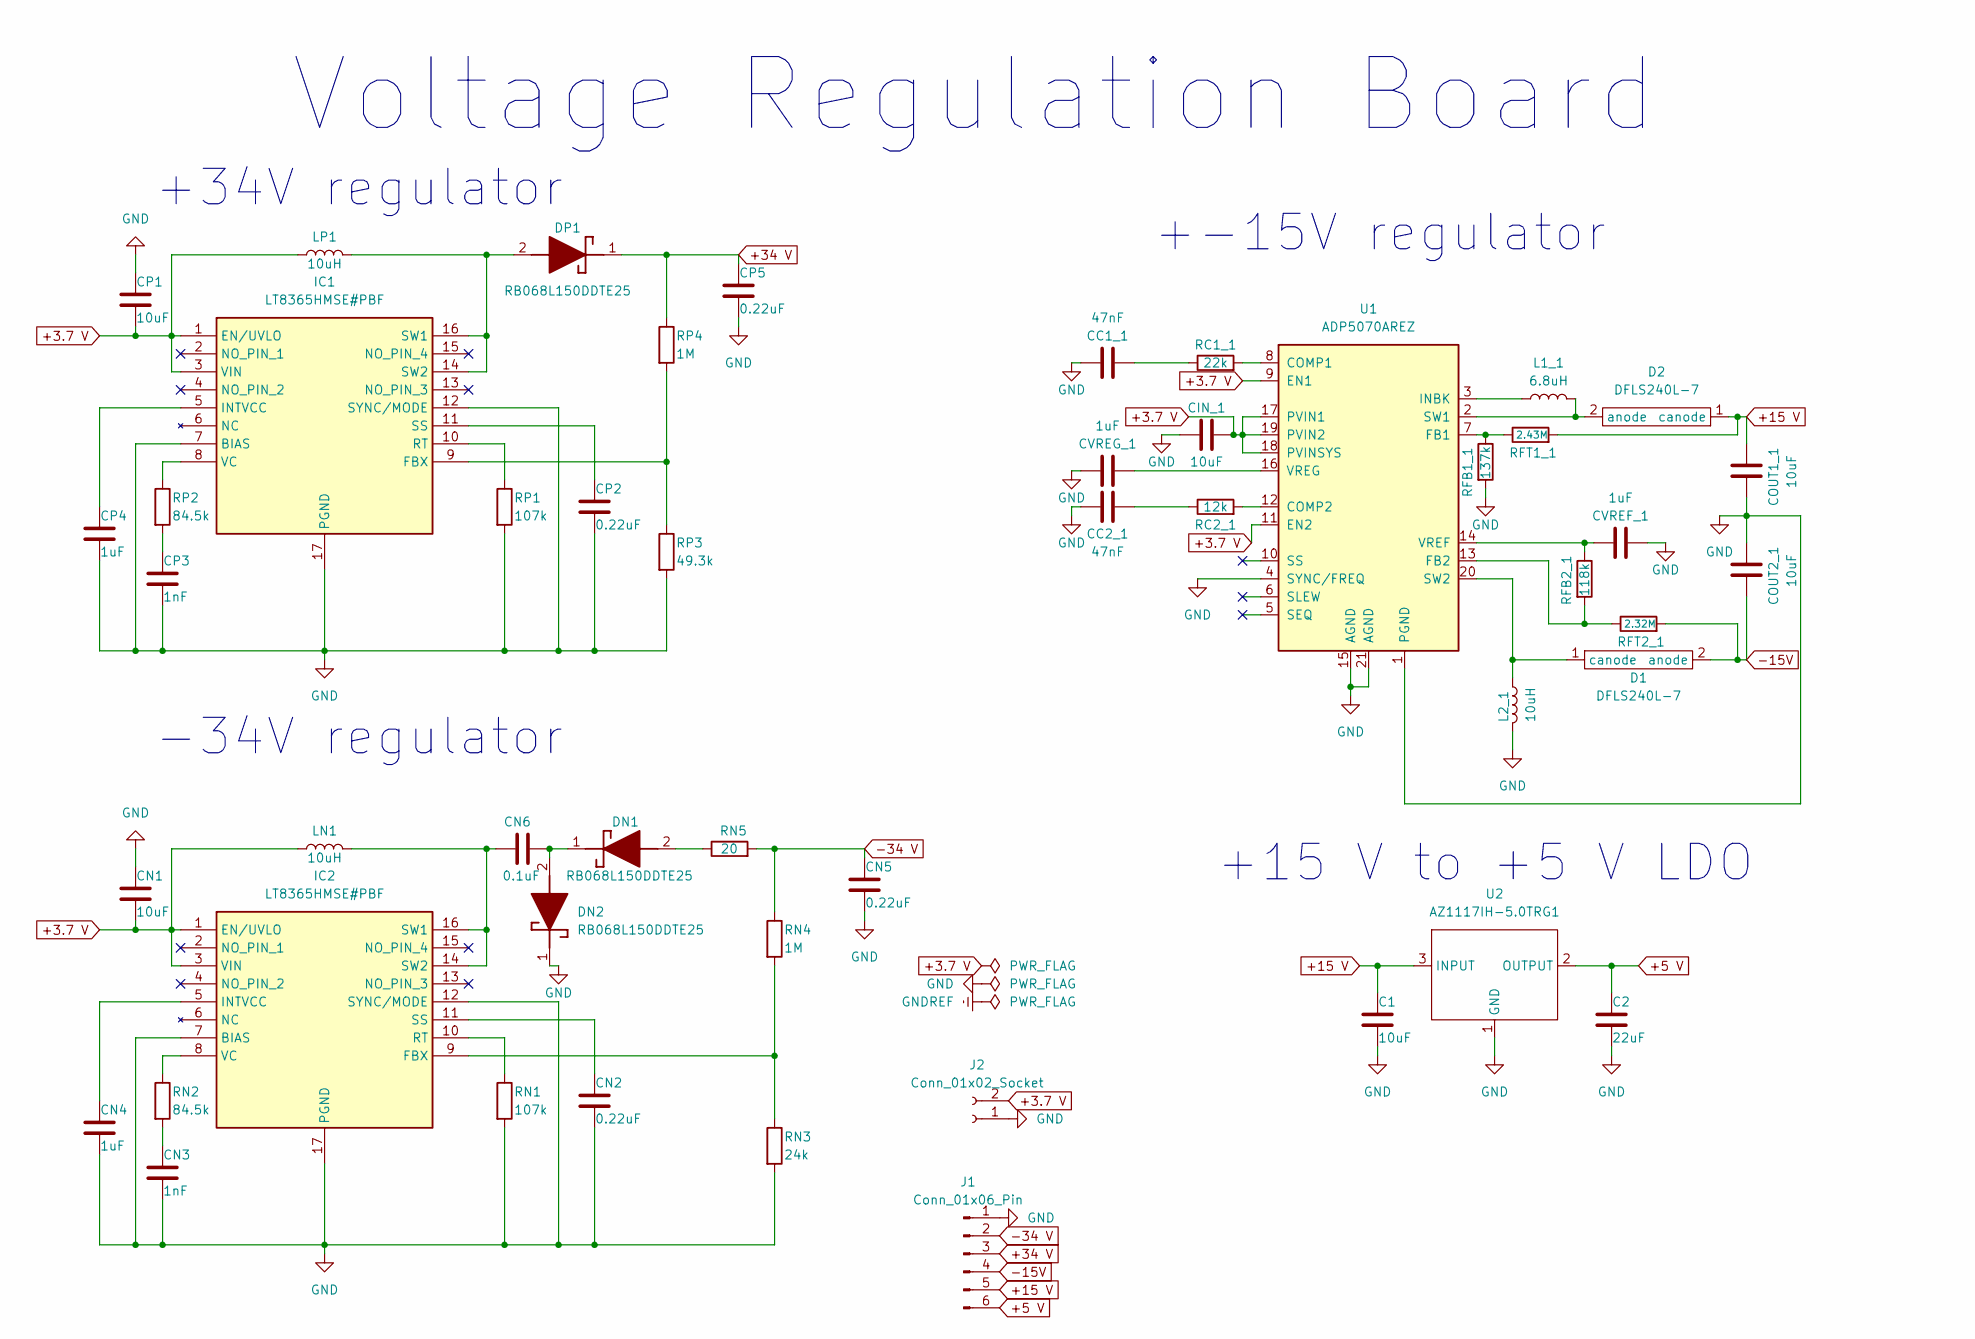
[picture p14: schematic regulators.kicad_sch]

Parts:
C1: 10uF; C_1210_3225Metric_Pad1.33x2.70mm_HandSolder
C2: 22uF; C_0805_2012Metric_Pad1.18x1.45mm_HandSolder
CC1_1, CC2_1: 47nF; C_0805_2012Metric_Pad1.18x1.45mm_HandSolder
CIN_1: 10uF; C_1210_3225Metric_Pad1.33x2.70mm_HandSolder
CN1: 10uF; C_1210_3225Metric_Pad1.33x2.70mm_HandSolder
CN2, CN5: 0.22uF; C_0805_2012Metric_Pad1.18x1.45mm_HandSolder
CN3: 1nF; C_0805_2012Metric_Pad1.18x1.45mm_HandSolder
CN4: 1uF; C_0805_2012Metric_Pad1.18x1.45mm_HandSolder
CN6: 0.1uF; C_0805_2012Metric_Pad1.18x1.45mm_HandSolder
COUT1_1, COUT2_1: 10uF; C_1210_3225Metric_Pad1.33x2.70mm_HandSolder
CP1: 10uF; C_1210_3225Metric_Pad1.33x2.70mm_HandSolder
CP2, CP5: 0.22uF; C_0805_2012Metric_Pad1.18x1.45mm_HandSolder
CP3: 1nF; C_0805_2012Metric_Pad1.18x1.45mm_HandSolder
CP4: 1uF; C_0805_2012Metric_Pad1.18x1.45mm_HandSolder
CVREF_1: 1uF; C_0805_2012Metric_Pad1.18x1.45mm_HandSolder
CVREG_1: 1uF; C_0805_2012Metric_Pad1.18x1.45mm_HandSolder
D1, D2: DFLS240L-7; D_PowerDI-123
DN1, DN2: RB068L150DDTE25; DIOM5026X220N; Mouser Part Number 755-RB068L150DDTE25
DP1: RB068L150DDTE25; DIOM5026X220N; Mouser Part Number 755-RB068L150DDTE25
IC1, IC2: LT8365HMSE#PBF; SOP50P490X110-17N; Mouser Part Number 584-LT8365HMSE#PBF
J1: Conn_01x06_Pin; PinHeader_1x06_P2.54mm_Horizontal
J2: Conn_01x02_Socket; PinSocket_1x02_P2.54mm_Horizontal
L1_1: 6.8uH; L_Coilcraft_XAL4040-XXX
L2_1: 10uH; L_Coilcraft_XAL4040-XXX
LN1: 10uH; L_Coilcraft_XAL4040-XXX
LP1: 10uH; L_Coilcraft_XAL4040-XXX
RC1_1: 22k; R_0805_2012Metric_Pad1.20x1.40mm_HandSolder
RC2_1: 12k; R_0805_2012Metric_Pad1.20x1.40mm_HandSolder
RFB1_1: 137k; R_0805_2012Metric_Pad1.20x1.40mm_HandSolder
RFB2_1: 118k; R_0805_2012Metric_Pad1.20x1.40mm_HandSolder
RFT1_1: 2.43M; R_0805_2012Metric_Pad1.20x1.40mm_HandSolder
RFT2_1: 2.32M; R_0805_2012Metric_Pad1.20x1.40mm_HandSolder
RN1: 107k; R_0805_2012Metric_Pad1.20x1.40mm_HandSolder
RN2: 84.5k; R_0805_2012Metric_Pad1.20x1.40mm_HandSolder
RN3: 24k; R_0805_2012Metric_Pad1.20x1.40mm_HandSolder
RN4: 1M; R_0805_2012Metric_Pad1.20x1.40mm_HandSolder
RN5: 20; R_0805_2012Metric_Pad1.20x1.40mm_HandSolder
RP1: 107k; R_0805_2012Metric_Pad1.20x1.40mm_HandSolder
RP2: 84.5k; R_0805_2012Metric_Pad1.20x1.40mm_HandSolder
RP3: 49.3k; R_0805_2012Metric_Pad1.20x1.40mm_HandSolder
RP4: 1M; R_0805_2012Metric_Pad1.20x1.40mm_HandSolder
U1: ADP5070AREZ; ETSSOP-20-1EP_4.4x6.5mm_P0.65mm_EP3x4.2mm
U2: AZ1117IH-5.0TRG1; SOT-223-3_TabPin2

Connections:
+3.7 V: CIN_1.2, CN1.2, CP1.2, IC1.1 (EN/UVLO), IC1.3 (VIN), IC2.1 (EN/UVLO), IC2.3 (VIN), J2.2, LN1.1, LP1.1, U1.9 (EN1), U1.11 (EN2), U1.17 (PVIN1), U1.18 (PVINSYS), U1.19 (PVIN2)
+5 V: C2.1, J1.6, U2.2 (OUTPUT)
+15 V: C1.1, COUT1_1.1, D2.1 (canode), J1.5, RFT1_1.2, U2.3 (INPUT)
+34 V: CP5.1, DP1.1 (K), J1.3, RP4.1
-15V: COUT2_1.2, D1.2 (anode), J1.4, RFT2_1.2
-34 V: CN5.1, J1.2, RN4.1, RN5.2
GND: C1.2, C2.2, CC1_1.1, CC2_1.1, CIN_1.1, CN1.1, CN2.2, CN3.2, CN4.2, CN5.2, COUT1_1.2, COUT2_1.1, CP1.1, CP2.2, CP3.2, CP4.2, CP5.2, CVREF_1.2, CVREG_1.1, DN2.1 (K), IC1.7 (BIAS), IC1.12 (SYNC/MODE), IC1.17 (PGND), IC2.7 (BIAS), IC2.12 (SYNC/MODE), IC2.17 (PGND), J1.1, J2.1, L2_1.2, RFB1_1.2, RN1.2, RN3.2, RP1.2, RP3.2, U1.1 (PGND), U1.4 (SYNC/FREQ), U1.15 (AGND), U1.21 (AGND), U2.1 (GND)
unnamed: CC1_1.2, RC1_1.1
unnamed: CC2_1.2, RC2_1.1
unnamed: CN3.1, RN2.2
unnamed: CP3.1, RP2.2
unnamed: D1.1 (canode), L2_1.1, U1.20 (SW2)
unnamed: D2.2 (anode), L1_1.2, U1.2 (SW1)
unnamed: DN1.2 (A), RN5.1
unnamed: CN6.2, DN1.1 (K), DN2.2 (A)
unnamed: DP1.2 (A), IC1.14 (SW2), IC1.16 (SW1), LP1.2
unnamed: IC1.9 (FBX), RP3.1, RP4.2
unnamed: CP4.1, IC1.5 (INTVCC)
unnamed: IC1.10 (RT), RP1.1
unnamed: CP2.1, IC1.11 (SS)
unnamed: IC1.8 (VC), RP2.1
unnamed: IC2.9 (FBX), RN3.1, RN4.2
unnamed: CN4.1, IC2.5 (INTVCC)
unnamed: IC2.10 (RT), RN1.1
unnamed: CN2.1, IC2.11 (SS)
unnamed: CN6.1, IC2.14 (SW2), IC2.16 (SW1), LN1.2
unnamed: IC2.8 (VC), RN2.1
unnamed: RC1_1.2, U1.8 (COMP1)
unnamed: RC2_1.2, U1.12 (COMP2)
unnamed: RFB1_1.1, RFT1_1.1, U1.7 (FB1)
unnamed: RFB2_1.2, RFT2_1.1, U1.13 (FB2)
unnamed: L1_1.1, U1.3 (INBK)
unnamed: CVREF_1.1, RFB2_1.1, U1.14 (VREF)
unnamed: CVREG_1.2, U1.16 (VREG)

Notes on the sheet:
Voltage Regulation Board
+34V regulator
+-15V regulator
-34V regulator
+15 V to +5 V LDO

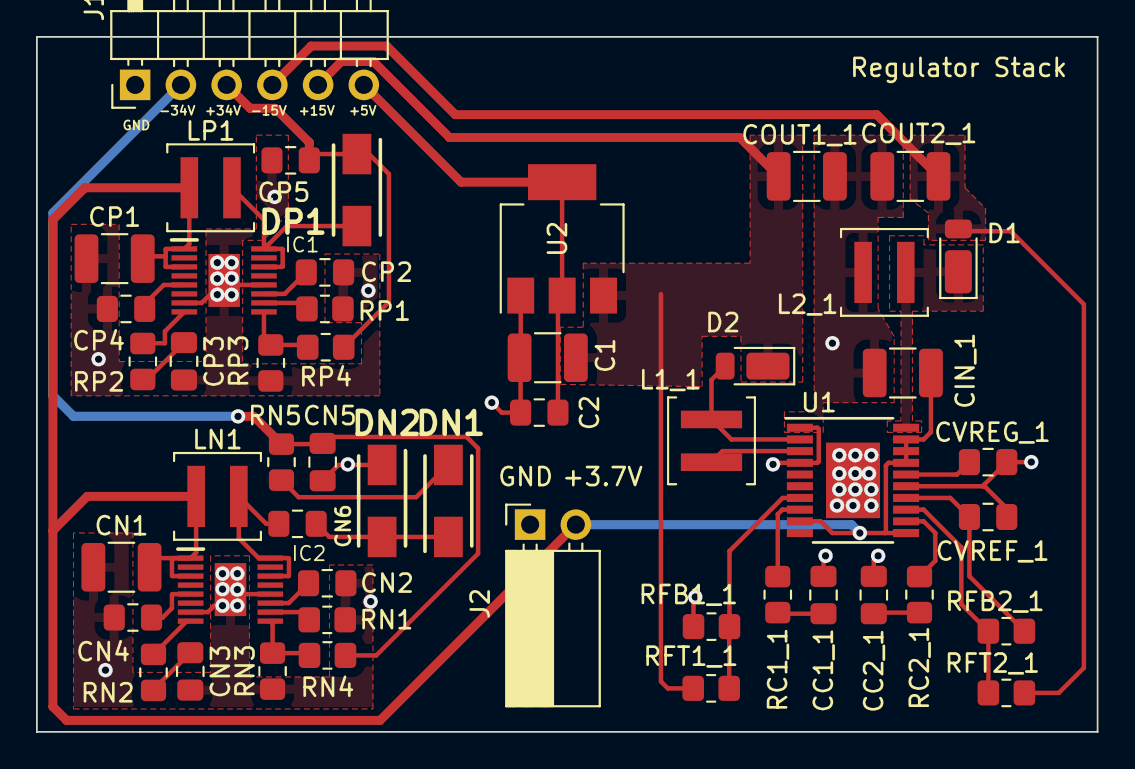
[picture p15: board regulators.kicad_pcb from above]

Board: 2 copper layers, 58.9 x 38.6 mm, 50 parts (0 on the bottom side), 34 nets.

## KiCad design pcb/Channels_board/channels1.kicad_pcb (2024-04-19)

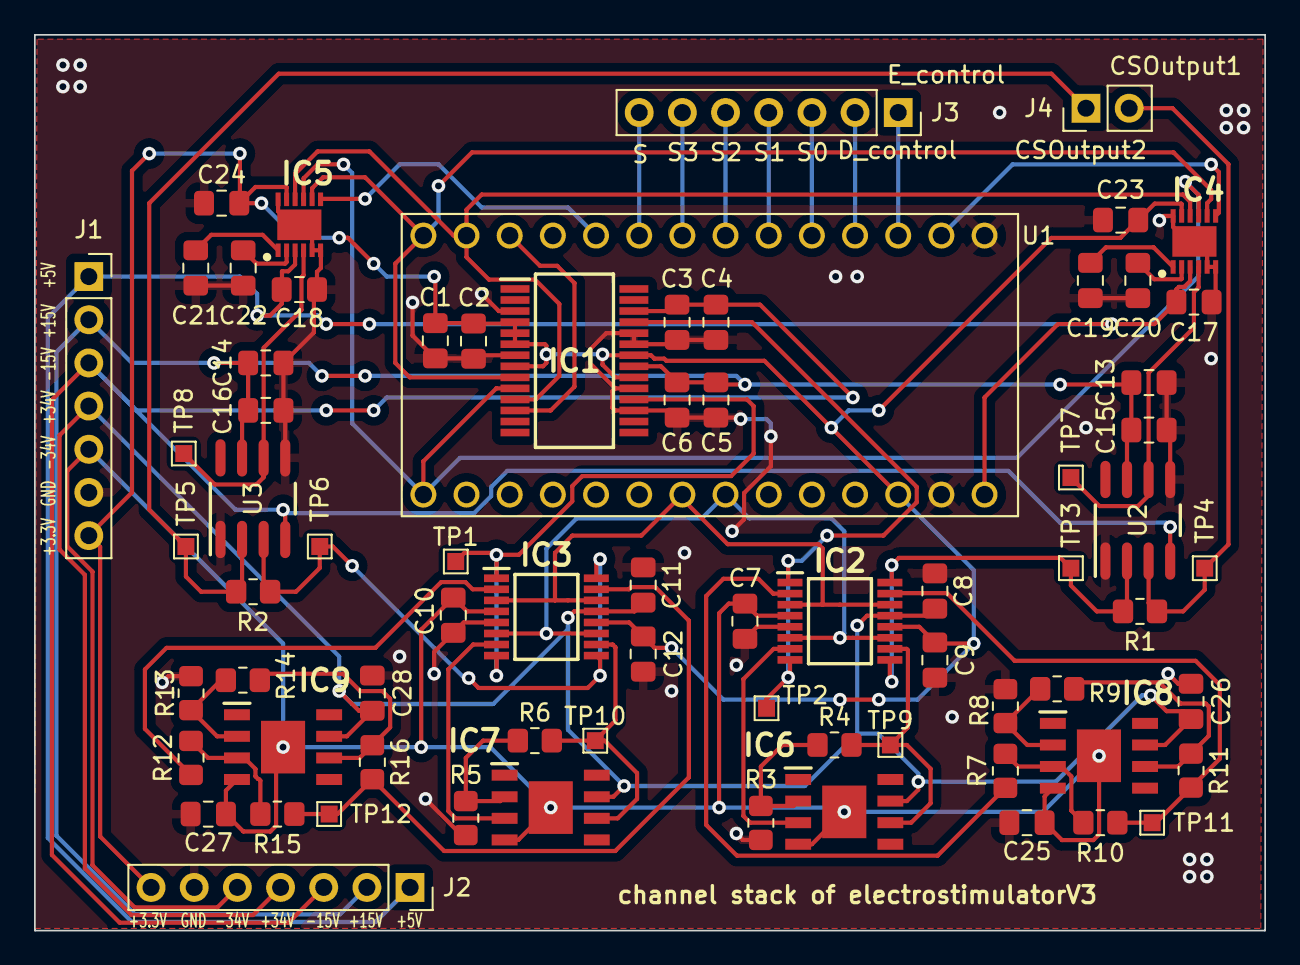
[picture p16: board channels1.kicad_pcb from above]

Board: 2 copper layers, 72.4 x 52.7 mm, 72 parts (0 on the bottom side), 50 nets.

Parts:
C1, C3, C5, C20, C22: 10uF; C_0805_2012Metric_Pad1.18x1.45mm_HandSolder
C2, C4, C6, C17, C18, C19, C21, C23, C24: 0.1uF; C_0805_2012Metric_Pad1.18x1.45mm_HandSolder
C7, C8, C9, C10, C11, C12, C13, C14: 1uF; C_0805_2012Metric_Pad1.18x1.45mm_HandSolder
C15, C16: 100 nF; C_0805_2012Metric_Pad1.18x1.45mm_HandSolder
C25, C26, C27, C28: 100nF; C_0805_2012Metric_Pad1.18x1.45mm_HandSolder
IC1: MAX5322EAI+; SOP65P778X199-28N
IC2, IC3: MAX14757EUE+T; SOP65P640X110-16N
IC4, IC5: MAX11156ETC+; SON50P300X300X80-13N
IC6, IC7, IC8, IC9: OPA455IDDA; SOIC127P600X170-9N
J1, J2, J3: Conn_01x07_Socket; PinSocket_1x07_P2.54mm_Vertical
J4: Conn_01x02_Pin; PinHeader_1x02_P2.54mm_Vertical
R1, R2: 240; R_0805_2012Metric_Pad1.20x1.40mm_HandSolder
R3, R5: 10k; R_0805_2012Metric_Pad1.20x1.40mm_HandSolder
R4, R6: 50k; R_0805_2012Metric_Pad1.20x1.40mm_HandSolder
R7, R12: 101k; R_0805_2012Metric_Pad1.20x1.40mm_HandSolder
R8, R9, R10, R13, R14, R15: 100k; R_0805_2012Metric_Pad1.20x1.40mm_HandSolder
R11, R16: 1k; R_0805_2012Metric_Pad1.20x1.40mm_HandSolder
TP1, TP2, TP3, TP4, TP5, TP6, TP7, TP8, TP9, TP10, TP11, TP12: TestPoint; TestPoint_Pad_1.0x1.0mm
U1: DEV-15583; MODULE_DEV-15583
U2, U3: INA149AID; D0008A_N

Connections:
+3.3V: C1.2, C2.2, C9.2, C12.2, C23.2, C24.2, IC1.4 (~SHDN), IC1.5 (~LDAC), IC1.6 (~CLR), IC1.8 (VCC), IC1.20 (REFA), IC1.22 (REFB), IC2.12 (VL), IC3.12 (VL), IC4.11 (OVDD), IC5.11 (OVDD), J1.7, J2.7, U1.3.3V_2
+5 V: C17.2, C18.2, IC4.3 (VDD), IC5.3 (VDD), J1.1, J2.1, U1.VIN
+15V: C5.1, C6.1, C13.1, C14.1, C15.1, C16.1, IC1.21 (VDD), J1.2, J2.2, U2.7 (V+), U3.7 (V+)
+34 V: C8.2, C11.2, C26.1, C28.1, IC2.13 (VDD), IC3.13 (VDD), IC6.7 (V+), IC7.7 (V+), IC8.7 (V+), IC9.7 (V+), J1.4, J2.4
-15V: C3.2, C4.2, IC1.26 (VSS), J1.3, J2.3, U2.4 (V-), U3.4 (V-)
-34 V: C7.2, C10.2, C25.1, C27.1, IC2.4 (VSS), IC3.4 (VSS), IC6.4 (V-), IC6.9 (EP), IC7.4 (V-), IC7.9 (EP), IC8.4 (V-), IC8.9 (EP), IC9.4 (V-), IC9.9 (EP), J1.5, J2.5
CSOutput1: J4.2, R1.2, TP4.1, U2.3 (IN+)
CSOutput2: J4.1, R2.1, TP5.1, U3.2 (IN-)
CSR_V1: IC4.4 (AIN+), TP7.1, U2.6 (VOUT)
CSR_V2: IC5.4 (AIN+), TP8.1, U3.6 (VOUT)
CsADC1: IC4.7 (CNVST), U1.0
CsADC2: IC5.7 (CNVST), U1.8
CsDAC: IC1.12 (~CS), U1.10
DAC Out 1: IC1.25 (OUTB), IC2.1 (A1), IC2.8 (A4), TP2.1
DAC Out 2: IC1.18 (OUTA), IC3.1 (A1), IC3.8 (A4), TP1.1
D_control: J3.2, U1.2
Din: IC1.11 (DIN), IC4.10 (DIN), IC5.10 (DIN), U1.11
Dout: IC1.9 (DOUT), IC4.8 (DOUT), IC5.8 (DOUT), U1.12
E_control: J3.1, U1.1
GND: C1.1, C2.1, C3.1, C4.1, C5.2, C6.2, C7.1, C8.1, C9.1, C10.1, C11.1, C12.1, C13.2, C14.2, C15.2, C16.2, C17.1, C18.1, C19.1, C20.1, C21.1, C22.1, C23.1, C24.1, C25.2, C26.2, C27.2, C28.2, IC1.3 (UNI/~BIPB), IC1.7 (DGND), IC1.17 (UNI/~BIPA), IC1.19 (SGNDA), IC1.23 (AGND), IC1.24 (SGNDB), IC2.5 (GND), IC3.5 (GND), IC4.5 (AIN-), IC4.6 (GND_1), IC4.12 (AGNDS), IC4.13 (GND_2), IC5.5 (AIN-), IC5.6 (GND_1), IC5.12 (AGNDS), IC5.13 (GND_2), J1.6, J2.6, R3.2, R5.2, R8.1, R13.1, U1.G1, U1.G3, U2.1 (REFB), U2.5 (REFA), U3.1 (REFB), U3.5 (REFA)
IO1: IC2.15 (B2), R10.2, R11.2, TP11.1
IO2: IC3.15 (B2), R15.2, R16.2, TP12.1
Input1: IC2.7 (B4), IC6.3 (+IN)
Input2: IC3.7 (B4), IC7.3 (+IN)
unnamed: C20.2, IC4.2 (REF)
unnamed: C19.2, IC4.1 (REFIO)
unnamed: C22.2, IC5.2 (REF)
unnamed: C21.2, IC5.1 (REFIO)
unnamed: IC6.2 (-IN), R3.1, R4.1
unnamed: IC7.2 (-IN), R5.1, R6.1
unnamed: IC8.3 (+IN), R7.2, R10.1
unnamed: IC8.2 (-IN), R8.2, R9.1
unnamed: IC8.6 (OUT), R9.2, R11.1
unnamed: IC9.3 (+IN), R12.2, R15.1
unnamed: IC9.2 (-IN), R13.2, R14.1
unnamed: IC9.6 (OUT), R14.2, R16.1
Output1: IC2.10 (B3), IC6.6 (OUT), R4.2, TP9.1
Output2: IC3.10 (B3), IC7.6 (OUT), R6.2, TP10.1
REF1: IC2.2 (B1), R7.1
REF2: IC3.2 (B1), R12.1
S: J3.7, U1.7
S0: J3.3, U1.3
S1: J3.4, U1.4
S2: J3.5, U1.5
S3: J3.6, U1.6
Sclk: IC1.10 (SCLK), IC4.9 (SCLK), IC5.9 (SCLK), U1.13
channel1: IC2.9 (A3), IC2.16 (A2), R1.1, TP3.1, U2.2 (IN-)
channel2: IC3.9 (A3), IC3.16 (A2), R2.2, TP6.1, U3.3 (IN+)
current mode: IC2.3 (EN1), IC2.14 (EN2), IC3.3 (EN1), IC3.14 (EN2), U1.19
voltage mode: IC2.6 (EN4), IC2.11 (EN3), IC3.6 (EN4), IC3.11 (EN3), U1.20

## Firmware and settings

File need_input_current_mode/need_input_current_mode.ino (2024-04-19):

#include <SPI.h>
const int CS_PIN = 10;  // chip select pin for DAC
const int CNSVT_PIN2 = 8;
const int CNSVT_PIN1 = 0;
const int cmode = 19;
uint32_t val;
float voltage;
SPISettings settingsA(10E6, MSBFIRST, SPI_MODE0);
SPISettings settingsB(20E6, MSBFIRST, SPI_MODE0);

// timer variables
unsigned long t0;
unsigned long t;
unsigned long t1;
unsigned long t2;
unsigned long save_time;

//control signals for muxs and d-latch
const int E_control = 1;
const int D_control = 2;
const int S = 7;
const int S0 = 3;
const int S1 = 4;
const int S2 = 5;
const int S3 = 6;

// Commands to DAC
uint16_t updateA = 8192;      //command to update register A in DAC
uint16_t updateB = 12288;     //command to update register B in DAC
uint16_t outputDACs = 40960;  // command to output from DACs
uint16_t poweron = 57344;     //command to power on the DACs
uint16_t DAC_value = 0;
uint16_t to_send;  // added uint16_t (update command + DAC value) that is sent by SPI to the DAC

int MUXtable[32][5] = {
  { 0, 0, 0, 0, 0 },  //0 : e1 to ch1
  { 0, 0, 0, 0, 1 },  //1 : e2 to ch1
  { 0, 0, 0, 1, 0 },  //2 : e3 to ch1
  { 0, 0, 0, 1, 1 },  //3 : e4 to ch1
  { 0, 0, 1, 0, 0 },  //4 : e5 to ch1
  { 0, 0, 1, 0, 1 },  //5 : e6 to ch1
  { 0, 0, 1, 1, 0 },  //6 : e7 to ch1
  { 0, 0, 1, 1, 1 },  //7 : e8 to ch1
  { 0, 1, 0, 0, 0 },  //8 : e9 to ch1
  { 0, 1, 0, 0, 1 },  //9 : e10 to ch1
  { 0, 1, 0, 1, 0 },  //10 : e11 to ch1
  { 0, 1, 0, 1, 1 },  //11 : e12 to ch1
  { 0, 1, 1, 0, 0 },  //12 : e13 to ch1
  { 0, 1, 1, 0, 1 },  //13 : e14 to ch1
  { 0, 1, 1, 1, 0 },  //14 : e15 to ch1
  { 0, 1, 1, 1, 1 },  //15 : e16 to ch1
  { 1, 0, 0, 0, 0 },  //16 : e1 to ch2
  { 1, 0, 0, 0, 1 },  //17 : e2 to ch2
  { 1, 0, 0, 1, 0 },  //18 : e3 to ch2
  { 1, 0, 0, 1, 1 },  //19 : e4 to ch2
  { 1, 0, 1, 0, 0 },  //20 : e5 to ch2
  { 1, 0, 1, 0, 1 },  //21 : e6 to ch2
  { 1, 0, 1, 1, 0 },  //22 : e7 to ch2
  { 1, 0, 1, 1, 1 },  //23 : e8 to ch2
  { 1, 1, 0, 0, 0 },  //24 : e9 to ch2
  { 1, 1, 0, 0, 1 },  //25 : e10 to ch2
  { 1, 1, 0, 1, 0 },  //26 : e11 to ch2
  { 1, 1, 0, 1, 1 },  //27 : e12 to ch2
  { 1, 1, 1, 0, 0 },  //28 : e13 to ch2
  { 1, 1, 1, 0, 1 },  //29 : e14 to ch2
  { 1, 1, 1, 1, 0 },  //30 : e15 to ch2
  { 1, 1, 1, 1, 1 }   //31 : e16 to ch2
};

int signalpin[] = { S, S3, S2, S1, S0 };

void setup() {
  // Setup teensy pins as outputs
  pinMode(CS_PIN, OUTPUT);  // chip select pin
  pinMode(CNSVT_PIN1, OUTPUT);
  pinMode(CNSVT_PIN2, OUTPUT);
  pinMode(cmode, OUTPUT);

  pinMode(S0, OUTPUT);
  pinMode(S1, OUTPUT);
  pinMode(S2, OUTPUT);
  pinMode(S3, OUTPUT);
  pinMode(S, OUTPUT);
  pinMode(D_control, OUTPUT);
  pinMode(E_control, OUTPUT);

  digitalWrite(CS_PIN, HIGH);
  digitalWrite(CNSVT_PIN1, HIGH);
  digitalWrite(CNSVT_PIN2, HIGH);

  digitalWrite(S0, LOW);
  digitalWrite(S1, LOW);
  digitalWrite(S2, LOW);
  digitalWrite(S3, LOW);
  digitalWrite(S, LOW);
  digitalWrite(D_control, LOW);
  digitalWrite(E_control, LOW);

  for (int i = 0; i < 32; i++) {
    for (int j = 0; j < 5; j++) {
      digitalWrite(signalpin[j], MUXtable[i][j]);
    }
    digitalWrite(E_control, HIGH);
    delay(10);
    digitalWrite(D_control, LOW);
    delay(10);
    digitalWrite(E_control, LOW);
    delay(10);
  }
  delay(100);

  // Begin SPI
  SPI.begin();
  Serial.begin(115200);

  digitalWrite(CNSVT_PIN1, LOW);
  SPI.beginTransaction(settingsA);
  SPI.transfer(00000000);
  SPI.endTransaction();
  digitalWrite(CNSVT_PIN1, HIGH);
  
  digitalWrite(CNSVT_PIN2, LOW);
  SPI.beginTransaction(settingsA);
  SPI.transfer(00000000);
  SPI.endTransaction();
  digitalWrite(CNSVT_PIN2, HIGH);

  // Power on both DACs
  digitalWrite(CS_PIN, LOW);        // disable chip select by default
  SPI.beginTransaction(settingsA);  // set the transaction settings
  SPI.transfer16(poweron);          // send the power on command
  SPI.endTransaction();
  digitalWrite(CS_PIN, HIGH);  // disable chip select by default

  digitalWrite(cmode, HIGH);
}
void loop() {
//this code is for voltage control mode
//a MATLAB live script controls this code to achieve real-time parameters modification


  setVoltages(2047, 2047);  // set voltages to 0 from the start

  // wait for message to start
  // look for 5 numbers sent by matlab in the following style "freq,amp,duration,electrode1,electrode2"
  while (Serial.available() > 0) {
    
    int freq = Serial.parseInt();//in Hz
    float amp = Serial.parseFloat();
    float T = 1e6 * (1.0 / freq);  //period in microseconds

    int dur = 0.5*1e6;//in microseconds
    unsigned long duration = dur;
    //How many 1/2 periods fit in the duration?


    float scaler = 1641;                                   //1236
    uint16_t DAC_value1 = 2047.0 + (scaler * amp / 32.0);  //1236
    uint16_t DAC_value2 = 2047.0 + (-scaler * amp / 32.0);



    switching(1,6);
    switching(2,11);
    

    // Connect ch1 to e1 and ch2 to e2
    //      (e1 ch 1)
    // digitalWrite(s0a, MUXtable[e1][0]);
    // digitalWrite(s3a, MUXtable[e1][3]);
    // digitalWrite(s4a, MUXtable[e1][2]);
    // digitalWrite(s5a, MUXtable[e1][1]);
    // //      (e2 ch 2)
    // digitalWrite(s0b, MUXtable[e2][0]);
    // digitalWrite(s3b, MUXtable[e2][3]);
    // digitalWrite(s4b, MUXtable[e2][2]);
    // digitalWrite(s5b, MUXtable[e2][1]);
    //if (1) {
    //start the main message once a new line is detected
    //digitalWrite(13, HIGH); // turn on indicator light
    //t = micros();  // record start time

    // while duration has not elapsed...
    if (Serial.read()=='\n') {
      t0 = micros();
      while (micros() - t0 < duration) {
        // every 1/2 period flip the phase
          t1 = micros();
          setVoltages(DAC_value1, DAC_value2);
          readADC_quiet();
          //delayMicroseconds(1);
          //readADC();
          while ((micros() - t1) < (T / 2)) {
            //delayMicroseconds(1);
            readADC();
          }  // wait for half a period to elapse
          

          t1 = micros();
          setVoltages(DAC_value2, DAC_value1);  // flip the voltages
          readADC_quiet();
          //delayMicroseconds(1);
          //readADC();
          while ((micros() - t1) < (T / 2)) {
            //delayMicroseconds(1);
            readADC();
          }  // wait for half a period to elapse
            

        
      }

      setVoltages(2047, 2047);
    }
  }
}

void setVoltages(uint16_t value1, uint16_t value2) {
  // Turn on DAC
  //Command 1: Update Input Register for Channel 1
  //digitalWrite(CNSVT_PIN, HIGH);
  digitalWrite(CS_PIN, LOW);
  SPI.beginTransaction(settingsA);
  to_send = updateA + value1;
  SPI.transfer16(to_send);
  SPI.endTransaction();
  digitalWrite(CS_PIN, HIGH);


  //Command 2: Update Input Register for Channel 2
  digitalWrite(CS_PIN, LOW);
  SPI.beginTransaction(settingsA);
  to_send = updateB + value2;
  SPI.transfer16(to_send);
  SPI.endTransaction();
  digitalWrite(CS_PIN, HIGH);


  //Command 3: Update both DAC Registers
  digitalWrite(CS_PIN, LOW);
  SPI.beginTransaction(settingsA);
  SPI.transfer16(outputDACs);
  SPI.endTransaction();
  digitalWrite(CS_PIN, HIGH);
}

void readADC() {
  digitalWrite(CS_PIN, HIGH);
  digitalWrite(CNSVT_PIN2, LOW);
  SPI.beginTransaction(settingsB);
  val = SPI.transfer32(0);
  SPI.endTransaction();
  val = val >> 14;
  voltage = val * 0.000038 - 5;
  //Serial.println(val * 0.000038 - 5);
  Serial.println(voltage);
  digitalWrite(CNSVT_PIN2, HIGH);
  
}

void readADC_quiet(){
  digitalWrite(CS_PIN, HIGH);
  digitalWrite(CNSVT_PIN2, LOW);
  SPI.beginTransaction(settingsB);
  val = SPI.transfer32(0);
  SPI.endTransaction();
  val = val >> 14;
  digitalWrite(CNSVT_PIN2, HIGH);
}

void readADC1() {
  digitalWrite(CS_PIN, HIGH);
  digitalWrite(CNSVT_PIN1, LOW);
  SPI.beginTransaction(settingsB);
  val = SPI.transfer32(0);
  SPI.endTransaction();
  val = val >> 14;
  voltage = val * 0.000038 - 5;
  Serial.println(voltage);
  digitalWrite(CNSVT_PIN1, HIGH);
  
}

void readADC_quiet1(){
  digitalWrite(CS_PIN, HIGH);
  digitalWrite(CNSVT_PIN1, LOW);
  SPI.beginTransaction(settingsB);
  val = SPI.transfer32(0);
  SPI.endTransaction();
  val = val >> 14;
  digitalWrite(CNSVT_PIN1, HIGH);
}

void switching(uint16_t ch, uint16_t e){
  uint16_t ind = (ch-1)*16 + e-1;
  //Serial.println(ind);
  for (int j = 0; j < 5; j++) {
    digitalWrite(signalpin[j], MUXtable[ind][j]);
  }
  digitalWrite(D_control, HIGH);
  delay(10);
  digitalWrite(E_control, HIGH);
  delay(10);
  digitalWrite(E_control, LOW);
  delay(10);
  digitalWrite(D_control, LOW);
  delay(10);
}

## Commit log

2024-04-19 add pcb design files
    [74LVC1G373DBVRE4.SchLib, 74LVC1G373DBVRE4.stp, AZ1117IH-5.0TRG1.SchLib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]
2024-04-19 add whole-time pulse arduino IDE sketches
2024-04-19 add code to evaluate switch speed
